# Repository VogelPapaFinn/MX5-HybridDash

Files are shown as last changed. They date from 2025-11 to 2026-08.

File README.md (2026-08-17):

# MX5-HybridDash (v2)

A hybrid instrument cluster for a *Mazda MX-5 NB*, which replaces the three small analog gauges and replaces them with 1.5" IPS displays. The project aims to look like an *OEM+* look and feel without destroying the old charm of the car.

<p align="center">
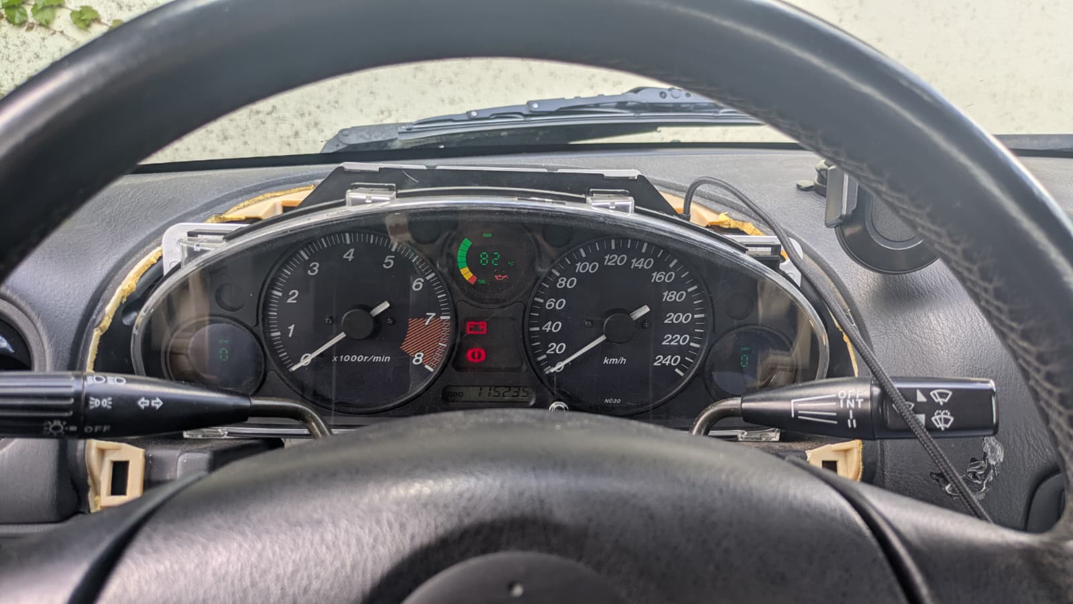
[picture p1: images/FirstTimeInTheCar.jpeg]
MX5 HybridDash Hardware
  
</p>

## Hardware

The project consists of four custom made PCBs of two types:
- A big Sensor PCB which sits on the back of the cluster, connects to the sensors & ECU and controls the displays
- Three small display PCBs which connect to the displays and receive instructions & data from the Sensor PCB

All four PCBs utilize a powerful ESP32-S3 microcontroller and the CAN bus to communicate with each other. This allows a robust communication without faulty data and provides the possiblity to expand the cluster with new hardware & features in the future-
The displays have a resolution of 360x360 on a 1.5" IPS panel, giving everything a high detailed look.

## Basic Features

Currently the displays can display:
* **RPM**
* **Speed**
* **Indicator (right & left)**
* **Oil Pressure (switch)**
* **Fuel Level**
* **Water Temperature**

This allows for example to calibrate the fuel level sensor so it is more accurate. In my car it shows that the fuel tank is empty when there are 10-15L left. Furthermore due to my size the indicators & the upper scale of the speedometer hide behind the steering wheel. By displaying them in the lower left and right display this isnt an issue anymore.

## Main Feature

My car is a pre-Facelift model and therefore does not have an OBDII connector (at least thats normal here in europe). After a lot of researching, fumbling around, reverse-engineering and testing I managed to establish a **connection** with the **OEM ECU** **without a OBDII connector**. 

At the moment I knowThis of 33 different values that are readable: *(Valus NOT Sensors, as some Sensors output multiple units)*
* **Alternator** - Load (%)
* **Alternator** - Desired Voltage (V)
* **Cabin Fan** - Toggle
* **Brake** - Toggle
* **Rear Window Defroster** - Toggle
* **Daytime Lights** - Toggle
* **Coolant** - Sensor Voltage (V)
* **Coolant** - Temperature (°C)
* **EGR** - Toggle
* **Cooling Fan Speed** - On, Slow Speed
* **Cooling Fan Speed** - On, Medium Speed
* **Cooling Fan Speed** - On, Fast Speed
* **Fuel Pump** - Toggle
* **Injector** - Injection Time (ms)
* **Battery** - Low Voltage (Light Indicator)
* **Headlight Left** - Toggle
* **Headlight Right** - Toggle
* **Idle Bypass** - Time (ms)
* **Idle Switch** - Toggle
* **Engine** - Load (%)
* **Airmass** (V)
* **Airmass** (g/s)
* **Main Relais** - Toggle
* **Engine** - Check Engine Light 
* **Airmass Pre-Cat** - Voltage (V)
* **Power Steering** - Pressure Switch Toggle
* **RPM**
* **EGR** - Valve Position
* **Ignition Timing** - Advancing (°)
* **Immobilizer** - Toggle
* **Throttle** - Voltage (V)
* **ECU** - Input Voltage (V)
* **Speed** (KMH)

## Future Plans
I plan a lot for the project even if its (software wise) stillt at the early beginning. But here is a list of features I aim to implement:
- [ ] Calibration of the sensors
- [ ] Calculation of new Values by combining the hardware & ECU sensors (e.g. current fuel consumption)
- [ ]  Webserver to control the dash
	- [ ] Reading & displaying data from the ECU
- [ ] Customizable display GUI
- [ ] Connection to the smartphone
	- [ ] Google Maps integration / direction notifications in the display GUI
	- [ ] Spotify integration
- [ ] Sensor data tracking & visualization for analyzation (e.g. on track-day use)

Please note that this are just some ideas of mine. This is not a roadmap. This is not organized by priority.

## About me

Hello! Im Finn a 21 year old computer science student from Bonn (Germany). I work as an embedded software engineer (besides my studies of course) and started tinkering around with electronics around two years ago. This project is developed exclusively in my free time for my own fun. I actually started just because I wanted to learn about electronics... Now here I am :)

## Contact

If you have any questions or anything else you are welcome to contact me. There are three possible ways (ranked by my preference):
1. send me a mail: finn.ganser@gmx.de
2. Create an issue here in this GitHub repository
3. Contact me via the Miata.net forum. Either via my linked thread or via a [private message](https://forum.miata.net/vb/member.php?u=307577)

## License

The whole project is published under the **GPLv3** license. Basically this means everybody can use, alter and provide the project, free and commercial as long as the provided code and hardware stays open source for the user. Note, that this is my conclusion of the license, before acting please read the license and its terms yourself!!

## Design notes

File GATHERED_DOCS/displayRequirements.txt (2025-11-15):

Minimum Requirements:
- Show RPM
- Show Speed
- Show Fuel level
- Show Blinkers
- Show Oil pressure
- Show Coolant temperature

- KM Total
- KM since start
- KM since last refueling
- Fuel consumption L/100km
- Fuel consumption %/100km
  
- Controlling the UI with buttons

Features which could be cool and not that complicated:
- Shift indicator
- Last shift on RPM X
- Tracking route, speed, acceleration etc. [and then send it to the smartphone or smth like that]
- 0kmh to 100kmh acceleration timer
- Welcome message on startup
- GPS speed

What would be nice but is probably not possible yet or really complicated:
- LED under needle which lights depending on the RPM/Speed/Fuel level/..
- Current fuel consumption (in this exact moment -> current fuel injection)
- Navigation from smartphone
- Show Speed limits (via GPS and web DB [Expert Level would be via live image recognition])
- Bluetooth audio connection (to radio)
- Dimming brightness with the dim switch in the car
- Configuring via App / WiFi / Website / ...
- Visual shift indicator via LEDs
- Visual last shift point via LEDs
- LED backlight for the whole cluster
- Replace the lighting icons with another display
(- Replace the old stepper motors with new ones and control them with the arduino)

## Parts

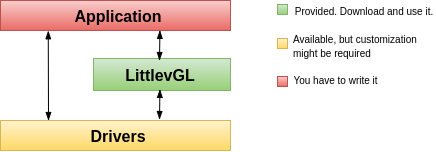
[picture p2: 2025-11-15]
SW/components/lvgl/docs/misc/sys.png

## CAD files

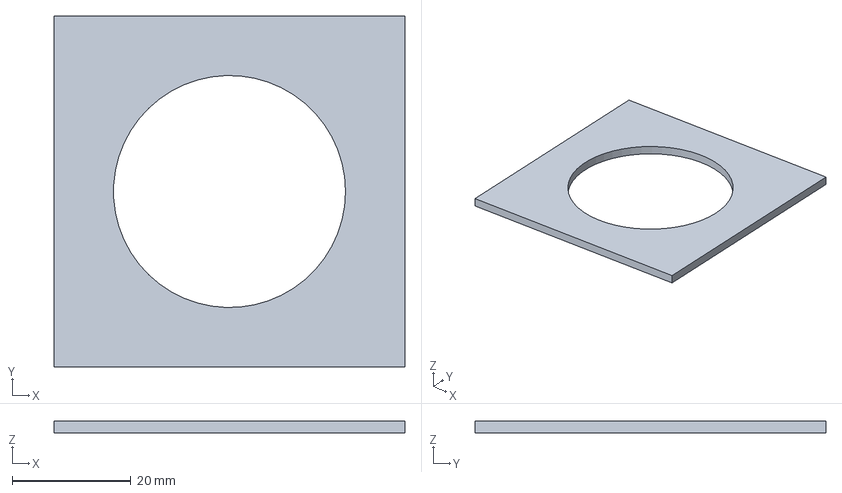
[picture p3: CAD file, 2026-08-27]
HW/3DModels/DisplayBracket.FCStd
59.0 x 59.0 x 2.00 mm

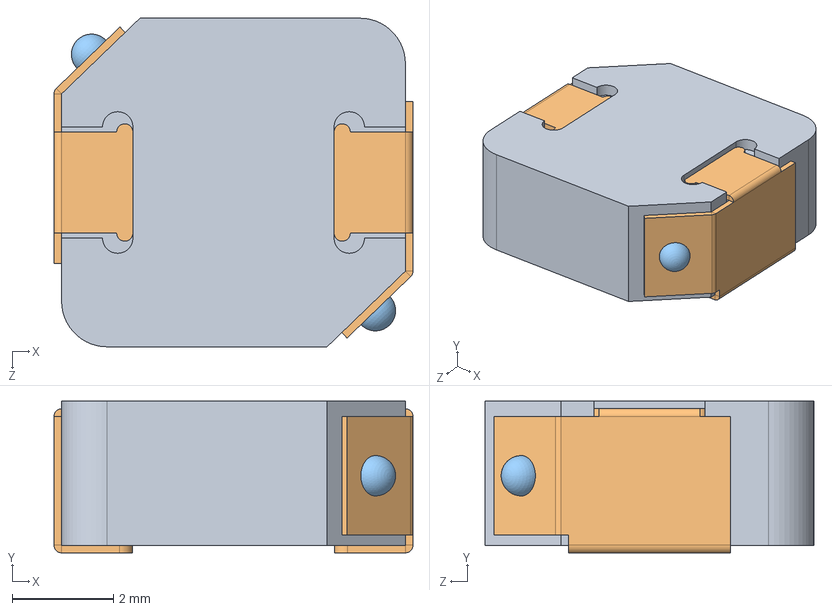
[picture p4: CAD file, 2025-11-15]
HW/Footprints/SPM6530T/SPM6530T-150M-HZ_uncolored.step
7.10 x 3.00 x 6.50 mm

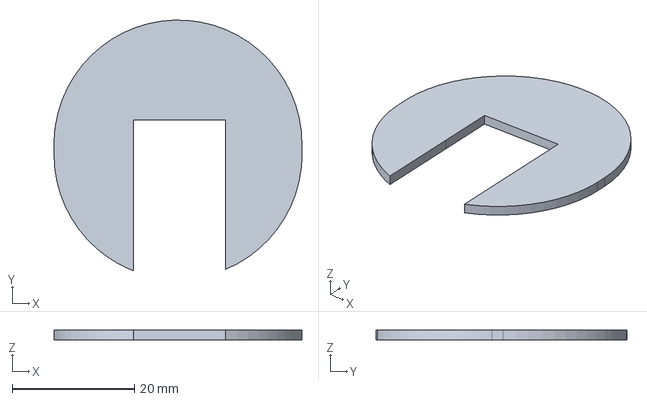
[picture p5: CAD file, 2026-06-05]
HW/3DModels/DisplaySpacer.FCStd
40.5 x 40.9 x 1.60 mm

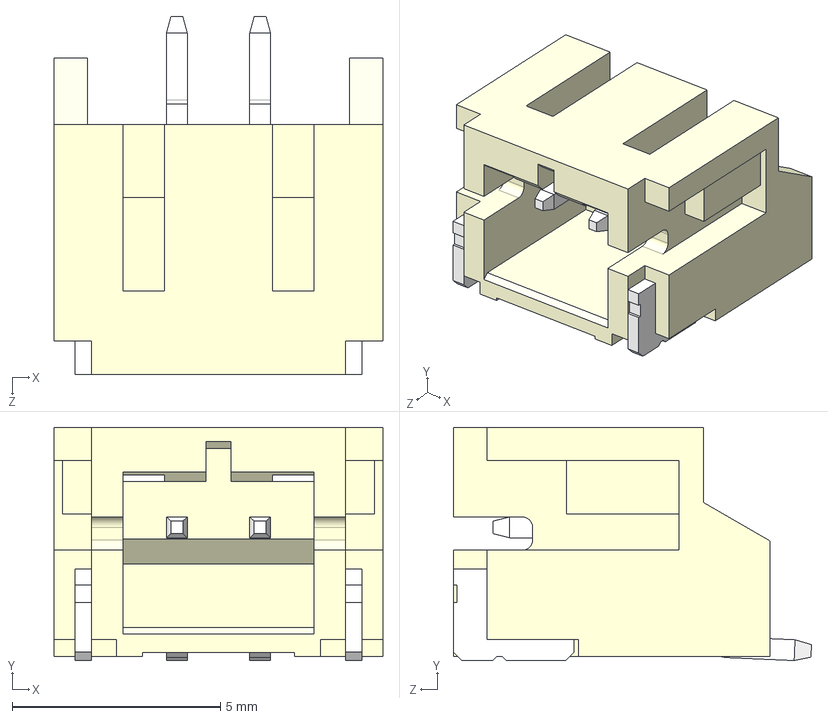
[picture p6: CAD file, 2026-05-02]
HW/3DModels/S2B-PH-SM4-TB--3DModel-STEP-269445.STEP
7.90 x 5.60 x 8.60 mm

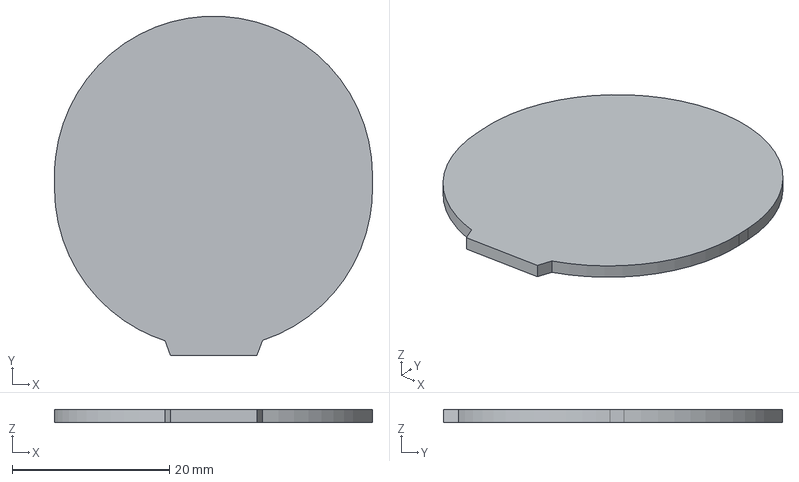
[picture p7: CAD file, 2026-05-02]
HW/3DModels/DisplayPCB.step
40.5 x 43.2 x 1.60 mm

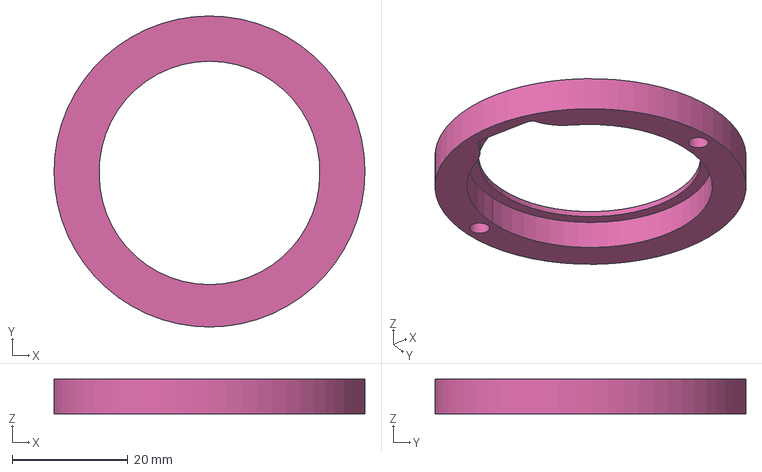
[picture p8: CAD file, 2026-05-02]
HW/3DModels/DisplayBracket-DisplayHolder.step
53.7 x 53.7 x 6.00 mm

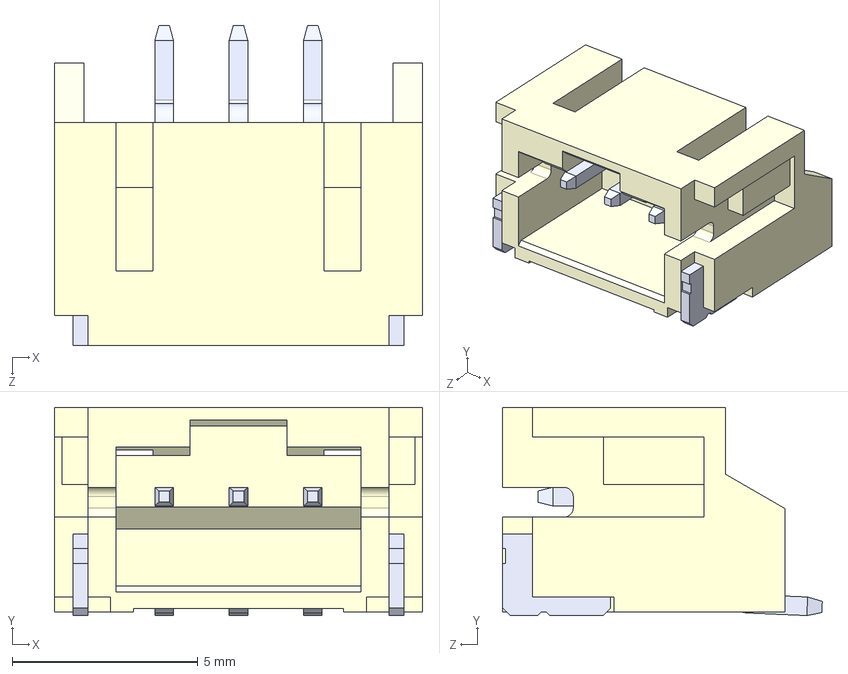
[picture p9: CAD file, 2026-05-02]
HW/3DModels/S3B-PH-SM4-TB--3DModel-STEP-269445.STEP
9.90 x 5.60 x 8.60 mm

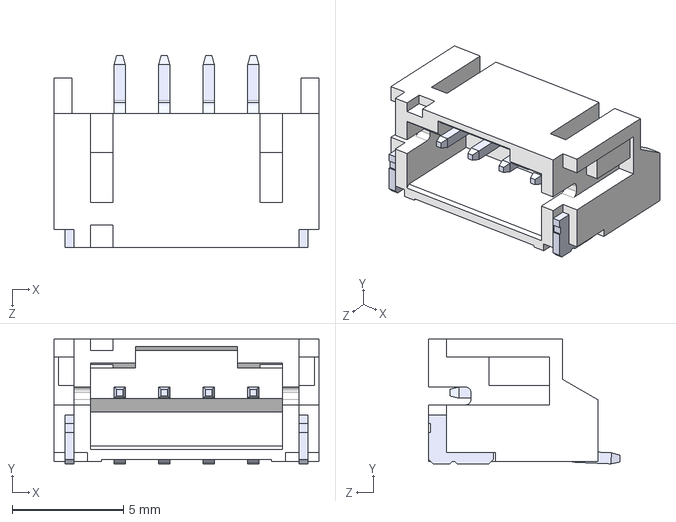
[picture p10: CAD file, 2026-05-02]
HW/3DModels/S4B-PH-SM4-TB--3DModel-STEP-56544.STEP
11.9 x 5.60 x 8.60 mm

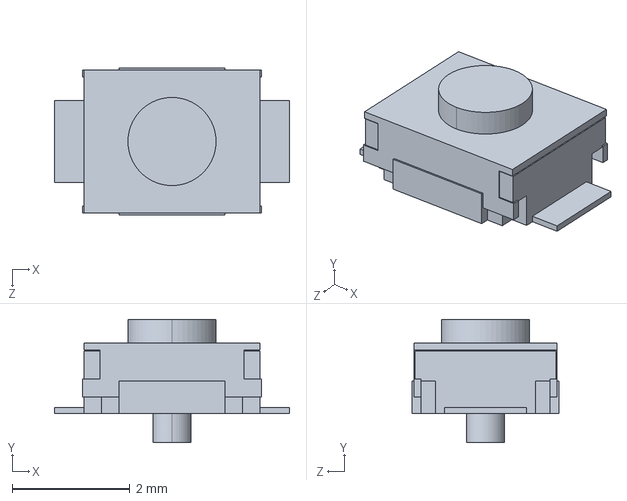
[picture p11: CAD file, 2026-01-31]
HW/3DModels/SMD_Push_Button.STEP
4.00 x 2.10 x 2.50 mm

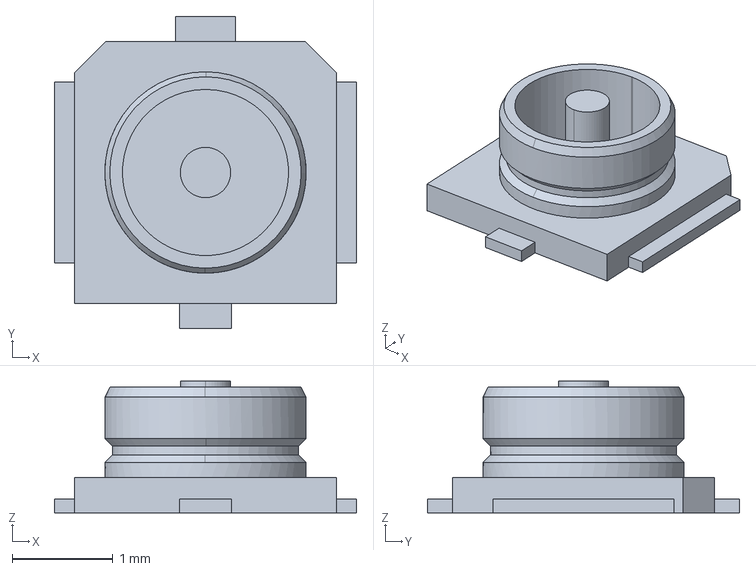
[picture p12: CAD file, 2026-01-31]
HW/3DModels/CONMHF1-SMD-G-T--3DModel-STEP-78480.STEP
3.00 x 3.10 x 1.31 mm

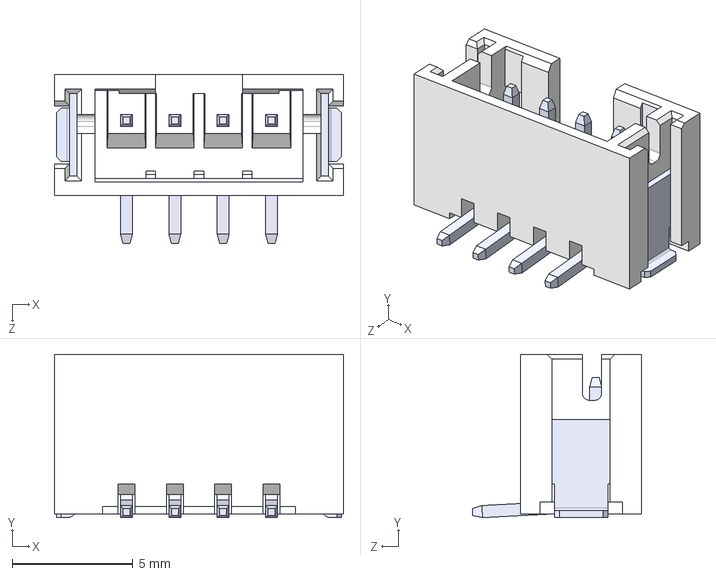
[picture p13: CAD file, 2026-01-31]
HW/3DModels/B4B-PH-SM4-TB--3DModel-STEP-510211.STEP
12.0 x 6.75 x 7.00 mm

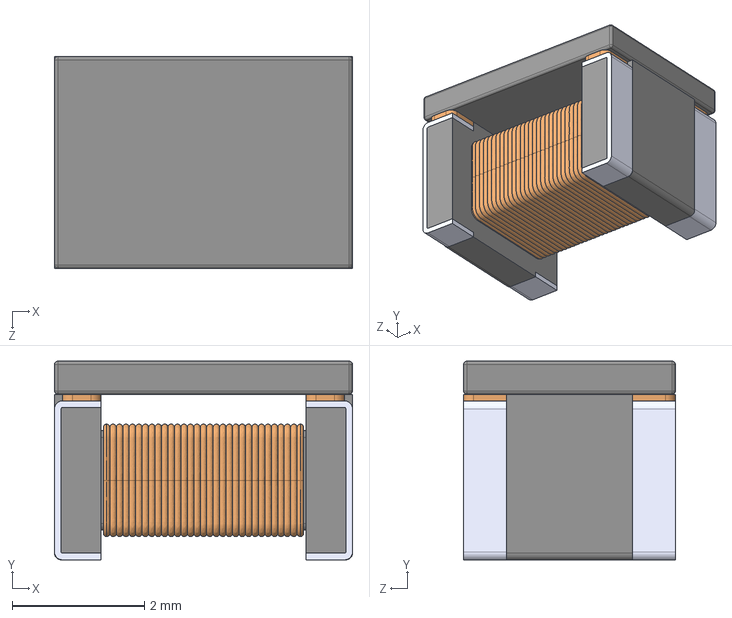
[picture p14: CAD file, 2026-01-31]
HW/3DModels/ACT45B-510-2P-TL003--3DModel-STEP-510211.STEP
4.50 x 3.00 x 3.20 mm

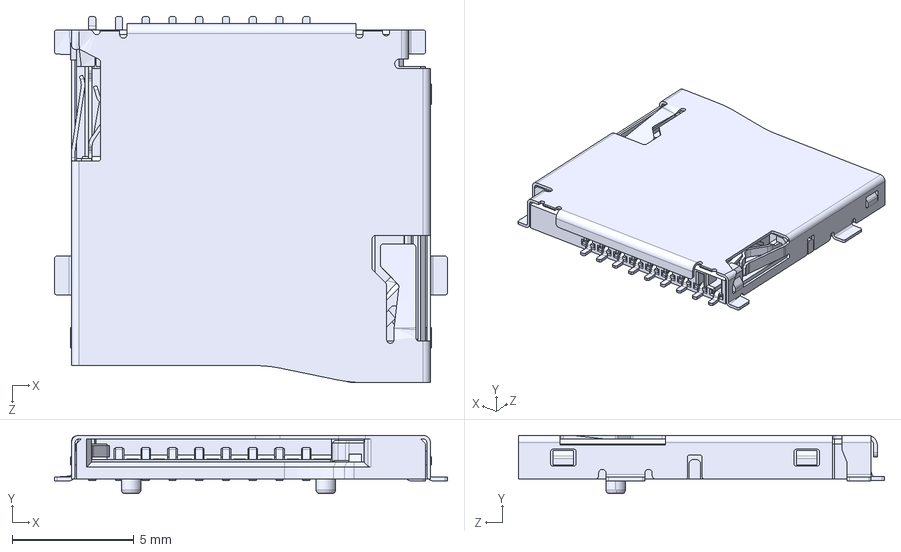
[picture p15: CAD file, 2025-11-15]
HW/3DModels/CUI_DEVICES_MSD-1-A.step
16.1 x 2.40 x 15.0 mm

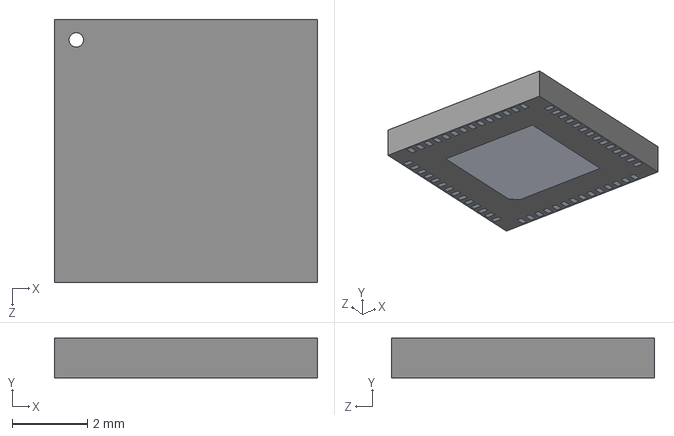
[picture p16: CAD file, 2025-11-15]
HW/3DModels/ESP32-S3-PICO-1-N8R2.step
7.00 x 1.06 x 7.00 mm

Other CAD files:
HW/3DModels/DisplayShape.FCStd
HW/3DModels/SPM6530T-150M-HZ.step
HW/3DModels/TPS5430DDAR.step
HW/3DModels/USB4105-GF-A.step
HW/3DModels/ESP32-S3-WROOM-1U 3D Model.STEP

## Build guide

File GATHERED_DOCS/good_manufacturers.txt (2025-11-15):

Allegro
Analog Devices
Broadcom
cal-chip
Diodes Incorporated
Diotec
epcos
Fairchild
Honeywell
Infineon
KEMET
KYOCERA AVX
Linear Technology
Microchip
Microsemi
Monolithic Power Systems
Motorola
Murata
National Semiconductor
Nexperia
NTE
NXP
onsemi
PANASONIC
Parallax
Renesas
Rochester Electronics
Rohm
Samsung
Sanken
Sanyo
Sharp
Stackpole
STMicroelectronics
Taiyo Yuden
TDK Electronics
TE
Texas Instruments/TI
Toshiba
Venkel
Viking Tech
Vishay
Wurth
Yageo

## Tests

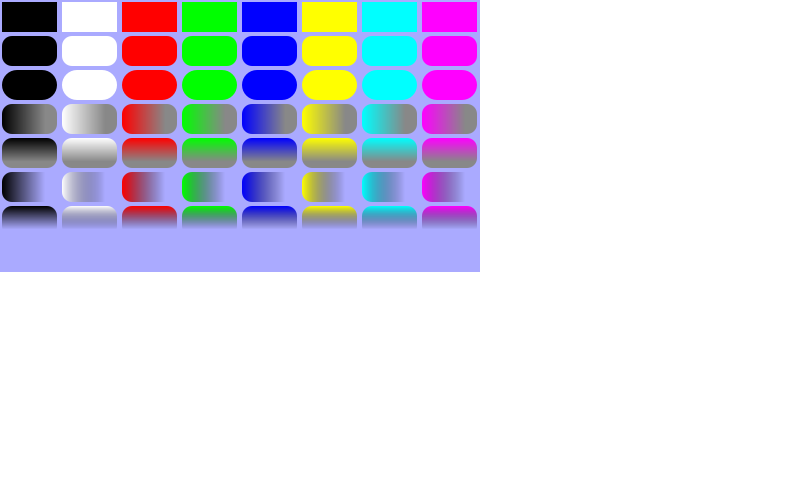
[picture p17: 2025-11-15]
SW/components/lvgl/tests/ref_imgs_vg_lite/draw/render/xrgb8888/demo_render_fill_opa_255.png

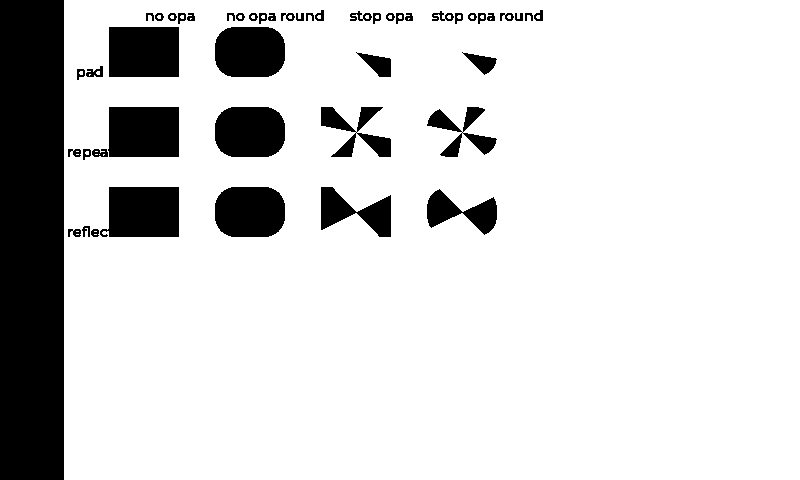
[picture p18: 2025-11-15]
SW/components/lvgl/tests/ref_imgs/draw/render/i1/demo_render_conical_gradient_opa_255.png

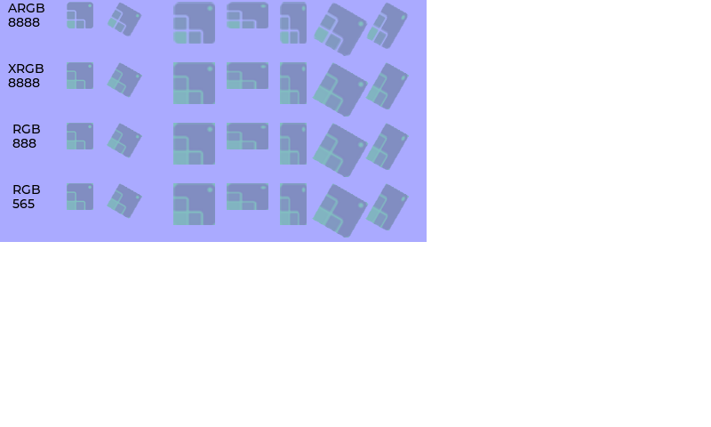
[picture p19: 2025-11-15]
SW/components/lvgl/tests/ref_imgs_vg_lite/draw/render/rgb888/demo_render_image_recolor_1_opa_128.png

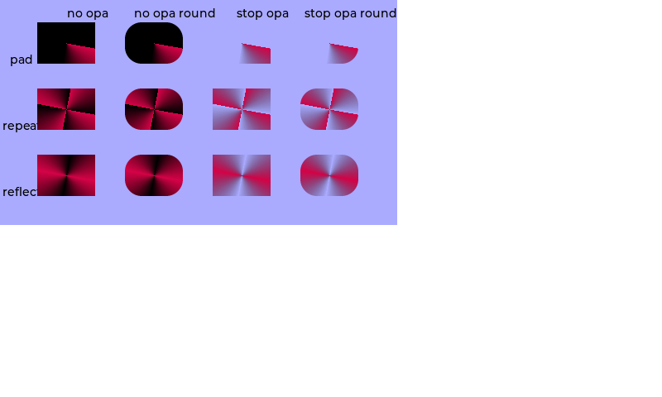
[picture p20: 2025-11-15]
SW/components/lvgl/tests/ref_imgs/draw/render/argb8888/demo_render_conical_gradient_opa_255.png

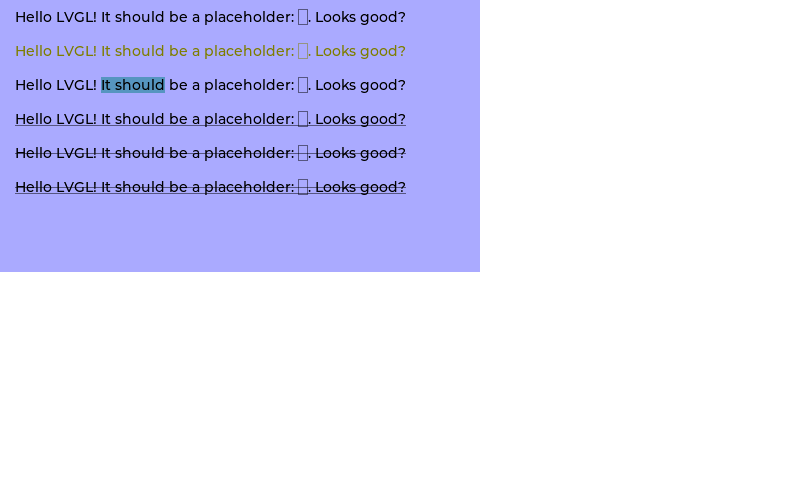
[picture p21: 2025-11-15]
SW/components/lvgl/tests/ref_imgs_vg_lite/draw/render/argb8888/demo_render_text_opa_128.png

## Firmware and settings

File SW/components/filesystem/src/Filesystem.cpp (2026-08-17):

#include "../Filesystem.hpp"

// C and C++ includes
#include <sys/stat.h>
#include <unistd.h>

// espidf includes
#include <bits/chrono.h>

#include "driver/gpio.h"

/*
 *	constexpr
 */
constexpr auto TAG = "Filesystem";

constexpr std::string SDCARD_BASE_PATH = "/sdcard";

constexpr std::string DATA_BASE_PATH = "/data";
constexpr std::string DATA_PARTITION_LABEL = "data";

constexpr std::string CONFIG_BASE_PATH = "/config";
constexpr std::string CONFIG_PARTITION_LABEL = "config";

constexpr gpio_num_t GPIO_CLK = GPIO_NUM_16;
constexpr gpio_num_t GPIO_CMD = GPIO_NUM_17;
constexpr gpio_num_t GPIO_D0 = GPIO_NUM_5;
constexpr gpio_num_t GPIO_D1 = GPIO_NUM_4;
constexpr gpio_num_t GPIO_D2 = GPIO_NUM_8;
constexpr gpio_num_t GPIO_D3 = GPIO_NUM_18;
constexpr uint8_t MAX_OPEN_FILES = 5;

/*
 *	Public Function Implementations
 */
Filesystem::Filesystem(bool mountSdCard, bool mountConfigPart, bool mountDataPart)
{
	bool warningOccured = false;
	bool errorOccured = false;

	/*
	 *	SD Card
	 */
	if (mountSdCard) {
		sdCardHost_.max_freq_khz = SDMMC_FREQ_HIGHSPEED; // 40 MHz
		sdCardHost_.slot = SDMMC_HOST_SLOT_0;

		sdCardSlotConfig_.width = 4;
		sdCardSlotConfig_.clk = GPIO_CLK;
		sdCardSlotConfig_.cmd = GPIO_CMD;
		sdCardSlotConfig_.d0 = GPIO_D0;
		sdCardSlotConfig_.d1 = GPIO_D1;
		sdCardSlotConfig_.d2 = GPIO_D2;
		sdCardSlotConfig_.d3 = GPIO_D3;

		sdCardMountConfig_.format_if_mount_failed = false;
		sdCardMountConfig_.max_files = MAX_OPEN_FILES;

		sdCardMounted_ = esp_vfs_fat_sdmmc_mount(SDCARD_BASE_PATH.c_str(), &sdCardHost_, &sdCardSlotConfig_,
												 &sdCardMountConfig_, &sdCardHandler_) == ESP_OK;
		if (sdCardMounted_) {
			ESP_LOGI(TAG, "Mounted SD Card");
		}
		else {
			ESP_LOGW(TAG, "Couldn't mount SD Card");
			warningOccured = true;
		}
	}

	/*
	 *	Data Partition
	 */
	if (mountDataPart) {
		dataPartConfig_.base_path = DATA_BASE_PATH.c_str();
		dataPartConfig_.partition_label = DATA_PARTITION_LABEL.c_str();
		dataPartConfig_.max_files = MAX_OPEN_FILES;
		dataPartConfig_.format_if_mount_failed = false;

		dataPartMounted_ = esp_vfs_spiffs_register(&dataPartConfig_) == ESP_OK;
		if (dataPartMounted_) {
			ESP_LOGI(TAG, "Mounted data partition");
		}
		else {
			ESP_LOGE(TAG, "Couldn't mount data partition");
			errorOccured = true;
		}
	}

	/*
	 *	Config Partition
	 */
	if (mountConfigPart) {
		configPartConfig_.base_path = CONFIG_BASE_PATH.c_str();
		configPartConfig_.partition_label = CONFIG_PARTITION_LABEL.c_str();
		configPartConfig_.max_files = MAX_OPEN_FILES;
		configPartConfig_.format_if_mount_failed = true;

		configPartMounted_ = esp_vfs_spiffs_register(&configPartConfig_) == ESP_OK;
		if (configPartMounted_) {
			ESP_LOGI(TAG, "Mounted config partition");
		}
		else {
			ESP_LOGE(TAG, "Couldn't mount config partition");
			errorOccured = true;
		}
	}

	if (warningOccured) {
		ESP_LOGW(TAG, "Initialized with warnings");
	}
	else if (errorOccured) {
		ESP_LOGE(TAG, "Initialized with errors");
	}
	else {
		ESP_LOGI(TAG, "Initialized");
	}
}

bool Filesystem::doesFileExist(const std::string& path, Location location) const
{
	if (!isLocationMounted(location)) {
		return false;
	}

	struct stat buffer;
	return stat(buildFullPath(path, location).c_str(), &buffer) == 0;
}

bool Filesystem::createFile(const std::string& path, const Location location)
{
	if (!isLocationMounted(location)) {
		ESP_LOGI(TAG, "Couldn't create file: Location %d not mounted", location);
		return false;
	}

	if (doesFileExist(path, location)) {
		return false;
	}

	// For whatever reason fopen crashes with test.txt. I have absolutely no clue why but it costed me quite a few
	// hours until I found the crashes are caused by this :C
	if (path == "test.txt") {
		return false;
	}

	const std::string fullPath = buildFullPath(path, location);

	FILE* file = fopen(fullPath.c_str(), "a+");
	if (file == nullptr) {
		ESP_LOGW(TAG, "Couldn't create file %s", fullPath.c_str());
		return false;
	}

	fclose(file);

	return true;
}

FILE* Filesystem::openFile(const std::string& path, const std::string& mode, Location location)
{
	if (!isLocationMounted(location)) {
		ESP_LOGI(TAG, "Couldn't open file: Location %d not mounted", location);
		return nullptr;
	}

	if (!doesFileExist(path, location)) {
		return nullptr;
	}

	const std::string fullPath = buildFullPath(path, location);

	FILE* file = fopen(fullPath.c_str(), mode.c_str());
	if (file == nullptr) {
		ESP_LOGW(TAG, "Couldn't open file %s", fullPath.c_str());
		return nullptr;
	}

	return file;
}

bool Filesystem::deleteFile(const std::string& path, const Location location)
{
	if (!isLocationMounted(location)) {
		ESP_LOGI(TAG, "Couldn't open file: Location %d not mounted", location);
		return false;
	}

	if (!doesFileExist(path, location)) {
		return false;
	}

	const std::string fullPath = buildFullPath(path, location);

	if (remove(fullPath.c_str()) != 0) {
		ESP_LOGW(TAG, "Couldn't delete file %s", fullPath.c_str());
		return false;
	}

	return true;
}

bool Filesystem::doesDirectoryExist(const std::string& path, Location location) const
{
	if (location != SD_CARD) {
		ESP_LOGW(TAG, "The spiffs file system does not support directories!");
		return false;
	}

	if (!isLocationMounted(SD_CARD)) {
		return false;
	}

	const std::string fullPath = buildFullPath(path, location);

	struct stat stats;
	stat(fullPath.c_str(), &stats);
	return S_ISDIR(stats.st_mode);
}

bool Filesystem::createDirectory(const std::string& path, Location location) const
{
	if (location != SD_CARD) {
		ESP_LOGW(TAG, "The spiffs file system does not support directories!");
		return false;
	}

	if (!isLocationMounted(SD_CARD)) {
		return false;
	}

	if (doesDirectoryExist(path, SD_CARD)) {
		return false;
	}

	const std::string fullPath = buildFullPath(path, location);

	if (mkdir(fullPath.c_str(), S_IRWXU) != 0) {
		ESP_LOGW(TAG, "Failed to create directory %s", fullPath.c_str());
		return false;
	}

	return true;
}

bool Filesystem::deleteDirectory(const std::string& path, Location location) const
{
	if (location != SD_CARD) {
		ESP_LOGW(TAG, "The spiffs file system does not support directories!");
		return false;
	}

	if (!isLocationMounted(SD_CARD)) {
		return false;
	}

	if (!doesDirectoryExist(path, SD_CARD)) {
		return false;
	}

	const std::string fullPath = buildFullPath(path, location);

	if (rmdir(fullPath.c_str()) != 0) {
		ESP_LOGW(TAG, "Couldn't delete directory %s", fullPath.c_str());
		return false;
	}

	return true;
}
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

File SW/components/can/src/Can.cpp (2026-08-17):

#include "Can.hpp"

// Project includes
#include "Events.hpp"

// espidf includes
#include "esp_event.h"
#include "esp_log.h"
#include "esp_twai.h"

/*
 *	Private constexpr
 */
constexpr auto TAG = "CanNode";

constexpr uint32_t CAN_SPEED = 1000000; // 1 Mbit/s
constexpr uint8_t CAN_QUEUE_DEPTH = 15;
constexpr uint16_t CAN_SEND_TIMEOUT_MS = 200;

/*
 *	Private Static Callback Functions
*/
static bool staticTransmittedFrameCb(twai_node_handle_t p_nodeHandle, const twai_tx_done_event_data_t* p_eventData,
									 void* p_userCtx)
{
	// Get the class context from the user arguments
	const auto can = static_cast<Can*>(p_userCtx);
	if (can == nullptr) {
		return false;
	}

	BaseType_t xHigherPriorityTaskWoken = pdFALSE;
	xQueueSendFromISR(*can->getFrameTransmittedQueue(), p_eventData->done_tx_frame, &xHigherPriorityTaskWoken);

	return xHigherPriorityTaskWoken;
}

static bool staticReceivedFrameCb(twai_node_handle_t p_nodeHandle, const twai_rx_done_event_data_t* p_eventData,
                                  void* p_userCtx)
{
	if (p_eventData == nullptr) {
		return false;
	}

	// Get the frame
	Can::Frame canFrame;
	twai_node_receive_from_isr(p_nodeHandle, &canFrame.twaiFrame);
	canFrame.fromTwaiFrame();

	// Queue it to the event loop
	esp_event_post(SYSTEM_EVENT_BASE, CAN_FRAME_RECEIVED, &canFrame, sizeof(canFrame), portMAX_DELAY);

	return false;
}

static bool staticStateChangedCb(twai_node_handle_t p_nodeHandle, const twai_state_change_event_data_t* p_eventData,
                                 void* p_userCtx)
{
	if (p_eventData == nullptr) {
		return false;
	}

	if (p_eventData->new_sta != TWAI_ERROR_BUS_OFF) {
		return false;
	}

	esp_rom_printf("State changed from %d to %d\n", p_eventData->old_sta, p_eventData->new_sta);
	// esp_rom_printf("An error occurred. Arbitration lost: %d \n Bit error: %d \n Form error: %d \n Stuff error: %d \n ACK error: %d \n val: %d", edata->err_flags.arb_lost, edata->err_flags.bit_err, edata->err_flags.form_err, edata->err_flags.stuff_err, edata->err_flags.ack_err, edata->err_flags.val);

	twai_node_recover(p_nodeHandle);

	return false;
}

/*
 *	Private Tasks
 */
static void canFrameTransmittedTask(void* p_param)
{
	if (p_param == nullptr) {
		vTaskDelete(nullptr);
	}

	auto can = static_cast<Can*>(p_param);

	twai_frame_t rxFrame;
	while (true) {
		if (xQueueReceive(*can->getFrameTransmittedQueue(), &rxFrame, portMAX_DELAY) != pdPASS) {
			continue;
		}

		can->transmittedFrameCb(rxFrame);
	}
}

/*
 *	Private Callback functions implementations
 */
void Can::transmittedFrameCb(const twai_frame_t frame)
{
	// Debug logging
	//esp_rom_printf("Transmitted frame with message id %d with buffer: ", p_eventData->done_tx_frame->header.id);
	//for (uint16_t i = 0; i < p_eventData->done_tx_frame->buffer_len; i++) {
	//	esp_rom_printf("%d ", p_eventData->done_tx_frame->buffer[i]);
	//}
	//esp_rom_printf("\n");

	if (xSemaphoreTake(pendingFramesMutex_, portMAX_DELAY) != pdTRUE) {
		return;
	}

	// Free memory
	for (uint32_t i = 0; i < pendingFrames_.size(); i++) {
		if (!pendingFrames_.at(i).get()->transmitting || pendingFrames_.at(i).get()->twaiFrame.header.id != frame.header.id) {
			continue;
		}

		auto const& pFrame = pendingFrames_.at(i).get()->twaiFrame;

		bool identical = true;

		// Header
		identical &= pFrame.header.id ==  frame.header.id;
		identical &= pFrame.header.dlc == frame.header.dlc;
		identical &= pFrame.header.brs == frame.header.brs;
		identical &= pFrame.header.esi == frame.header.esi;
		identical &= pFrame.header.fdf == frame.header.fdf;
		identical &= pFrame.header.ide == frame.header.ide;
		identical &= pFrame.header.rtr == frame.header.rtr;

		// Data
		identical &= pFrame.buffer_len == frame.buffer_len;
		if (!identical) { continue; }
		for (uint8_t j = 0; j < pFrame.buffer_len; j++) {
			identical &= pFrame.buffer[j] == frame.buffer[j];
		}

		if (!identical) { continue; }

		pendingFrames_.erase(pendingFrames_.begin() + i);

		// Unlock the mutex
		xSemaphoreGive(pendingFramesMutex_);

		return;
	}

	// Unlock the mutex
	xSemaphoreGive(pendingFramesMutex_);
}

/*
 *	Private Function implementations
 */
Can::Can(const gpio_num_t rxGpio, const gpio_num_t txGpio)
{
	rxGpio_ = rxGpio;
	txGpio_ = txGpio;

	nodeHandle_ = nullptr;

	nodeConfig_.io_cfg.rx = rxGpio_;
	nodeConfig_.io_cfg.tx = txGpio_;
	nodeConfig_.bit_timing.bitrate = CAN_SPEED;
	nodeConfig_.tx_queue_depth = CAN_QUEUE_DEPTH;
	nodeConfig_.intr_priority = ESP_INTR_FLAG_LEVEL1;

	nodeCallbacks_.on_tx_done = staticTransmittedFrameCb;
	nodeCallbacks_.on_rx_done = staticReceivedFrameCb;
	nodeCallbacks_.on_state_change = staticStateChangedCb;
	nodeCallbacks_.on_error = nullptr;

	pendingFramesMutex_ = xSemaphoreCreateMutex();
}

bool Can::initialize()
{
	if (rxGpio_ == GPIO_NUM_NC || txGpio_ == GPIO_NUM_NC) {
		return false;
	}

	if (twai_new_node_onchip(&nodeConfig_, &nodeHandle_) != ESP_OK) {
		ESP_LOGE(TAG, "Failed to initialize CAN node");
		return false;
	}

	if (twai_node_register_event_callbacks(nodeHandle_, &nodeCallbacks_, this) != ESP_OK) {
		// Cleanup
		twai_node_delete(nodeHandle_);

		ESP_LOGE(TAG, "Failed to register CAN node callbacks");
		return false;
	}

	/*
	 *	Create Task & Queue needed to handle the memory when a frame was transmitted
	 */
	frameTransmittedQueueHandle_ = xQueueCreate(CAN_QUEUE_DEPTH, sizeof(twai_frame_t));

	if (xTaskCreate(canFrameTransmittedTask, "CanFrameTransmittedTask", 2048, this, 2, &frameTransmittedTaskHandle_) != pdPASS) {
		ESP_LOGE(TAG, "Failed to create can frame transmitted task");
		esp_restart();
	}

	ESP_LOGI(TAG, "Initialized CAN node");

	return true;
}

void Can::deinitialize() const
{
	if (nodeHandle_ == nullptr) {
		return;
	}

	// There is no function for unregistering the callbacks, so simply delete the node
	twai_node_delete(nodeHandle_);

	ESP_LOGI(TAG, "Deinitialized CAN node");
}

bool Can::enable()
{
	if (nodeHandle_ == nullptr || enabled_) {
		return false;
	}

	enabled_ = twai_node_enable(nodeHandle_) == ESP_OK;
	if (!enabled_) {
		ESP_LOGE(TAG, "Failed to enable CAN node");
	}
	else {
		ESP_LOGI(TAG, "Enabled CAN node");
	}

	return enabled_;
}

void Can::queueFrame(Frame& canFrame)
{
	if (!enabled_) {
		return;
	}

	canFrame.transmitting = true;

	// ESP_LOGI(TAG, "Transmitting Frame %s", canFrame.toString().c_str());

	// Acquire the mutex lock
	if (xSemaphoreTake(pendingFramesMutex_, portMAX_DELAY) != pdTRUE) {
		return;
	}

	// Track the new frame
	pendingFrames_.push_back(std::make_shared<Frame>(canFrame));
	const auto trackedFrame = pendingFrames_.back().get();
	trackedFrame->buildTwaiFrame();

	// Unlock the mutex
	xSemaphoreGive(pendingFramesMutex_);

	if (twai_node_transmit(nodeHandle_, &trackedFrame->twaiFrame, CAN_SEND_TIMEOUT_MS) != ESP_OK) {
		ESP_LOGW(TAG, "Failed to queue CAN frame");
	}
}

QueueHandle_t* Can::getFrameTransmittedQueue()
{
	return &frameTransmittedQueueHandle_;
}

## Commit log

2025-11-16 Removed idf.bat; Updated submodules; Implemented can bus components with basic transmit/receive functionality
2025-11-23 Updated FW; Added .clang-format for espidf components;Added first few CAN Messages;Readded Logger as component;
    [CANBus_Messages.xlsx]
2025-12-08 Updated DisplayBoard Firmware; Updated SensorBoard Firmware; Implemented basic statemachine; Changed how the CAN lib works
    [CANBus_Messages.xlsx]
2026-01-04 Updated DisplayBoard and SensorBoard Firmware; Implemented CAN bus recovery request; Removed logger component; Applied clang-tidy rules
2026-01-04 Updated Display and Sensor firmware
2026-01-06 Added firmware version request CAN logic; Added deactivated CAN debugging function; Updated Sensor and Display firmware]
2026-01-09 Reworked CAN system; Removed state machine component; Updated SensorBoard and DisplayBoard firmware
2026-01-10 Updated SensorBoard firmware; Added unregister rx cb function in the CAN
2026-01-10 Changed name of CAN message; Updated Display and Sensor Board firmware
2026-01-11 Changed how the CAN passes rx frames; Fixed NULL pointer exception; Fixed brs = 1 bug
2026-01-17 Fixed a bug where received CAN data was sometimes out of scope; Updated Sensor and Display Board firmware
2026-01-19 Updated Display and Sensor Board firmware
2026-01-31 Reworked Display Board circuitry and layout
    [ACT45B-510-2P-TL003--3DModel-STEP-510211.STEP, B4B-PH-SM4-TB--3DModel-STEP-510211.STEP, CONMHF1-SMD-G-T--3DModel-STEP-78480.STEP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]
2026-02-01 Updated SensorBoard HW
2026-05-02 Added rewritten Filesystem component; Rewritten CAN component; Updated 3D Models, Footprints etc.; Added PDF for KLine protocol (communication with ECU, which is confirmed to be working but not yet i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
    [CUI_DEVICES_MSD-1-A.step, DisplayBracket-DisplayHolder.step, DisplayBracket.FCStd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]
2026-05-02 Updated DisplayPCB , SensorBoardPCB and SensorBoardFW submodules
2026-05-08 Changed CAN header structure; Fixed dangling pointer when sending data; Fixed issue where data was send but nothing was received; Updated UI
    [DisplayBracket.FCStd]
2026-05-08 Moved the Config class from the SensorBoard FW to the Filesystem component; Fixed issue in the Filesystem component
    [Filesystem.cpp]
2026-06-05 Updated CAN Driver; Updated Config File Driver; Updated EEZ Project
    [DisplayBracket.FCStd, DisplaySpacer.FCStd]
2026-06-07 Removed debugging log from CAN driver; Updated Display Firmware; Updated Sensorboard Firmware; Added MX5NB service manual;
2026-06-12 Fixed racing issue in the CAN driver; Moved Wifi driver to its own espidf component; Updated Display and Sensor Board FW
    [Can.cpp]
2026-06-13 Deactivated logging in the CAN driver; Fixed issue in the WifiHost driver; Updated Display & Sensor PCB firmware
    [Can.cpp]
2026-08-17 Complete rework of event & task system. Now using espidf event loop and FreeRTOS timers (UNTESTED!!!); Further code improvements, with the goal modulize/separater the code; Display SW not yet reworke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
    [Can.cpp, Filesystem.cpp]
2026-08-17 Fixed cashes & startup issues
    [Can.cpp]
2026-08-17 Fixed crash in the wifi drivers
2026-08-27 Simplified display registration;
    [DisplayBracket.FCStd]
2026-08-27 Updated Display and Sensor PCB firmware
2026-10-10 Added clangd file; Updated Display Bracket 3D Model (Rework needed!); Switched from espidf src clone to docker container
2026-10-10 Updated SensorBoard_FW; clang formatted Can.hpp
2026-10-10 Added clangd file; Switched to devcontainer & vscode; clang formatted Gui.hpp;
2026-10-17 Added SensorsData singleton class, which holds the newest data of each sensor; Added SensorHandler which handles the HW Sensors, updates them and writes their new values into the SensorsData object; 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
2026-10-17 Updated how the CAN Driver reports received frames
2026-10-18 WIP StateMachine implementation; WIP rework of all states; Implemented Sensor Broadcasting (UNTESTED)
2026-10-19 WIP StateMachine Implementation in the SensorBoard_FW; Reformattings
2026-10-21 Updated CAN Groups and Functions for the new states in the SensorBoard_FW; Updated MessageReceiver to prevent duplicated Code; Updated SensorBoard_FW
2026-10-23 WIP StateMachine implementation (UNTESTED!!!); Implemented Configuration state; Added default config as .hpp; "Reworked" Gui and renamed it to GuiHandler; Implemented Operation state; "Reworked" ST77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
2026-10-23 CAN observers now dont attach to a group but to CAN in general, as there can now be only one observer at a time; Updated DisplayBoard_FW and SensorBoard_FW
2026-10-24 Added print function to the Config class; Improved closing of Config class; Updated DisplayBoard_FW and SensorBoard_FW
2026-10-24 Moved ADC init from Startup State to main; Deactivated 2 out of 3 displays for debugging; Fixed issue where the FirstStartup flag wouldnt be set to false after configuring
2026-10-24 Improved toString method of Can component; Updated DisplayBoard_FW and SensorBoard_FW
2026-10-24 Tasks now dont simply get deleted but notified and end themselves to prevent memory leaks, undefined states etc.; Renames SensorsData and SensorHandler; Added new SensorBroadcaster
2026-10-24 Fixed memory leak in CAN driver; Fixed crash caused by config class; Updated both Firmwares
2026-10-30 Verified basic KLine functionality; 5-baud init not working with current IC (TJA1021 due to TX dominant timeout being too low);
2026-10-30 Removed not needed keep alive kline frame
2026-10-31 Updated ECU sensor architecture
2026-10-31 Added names of ECU sensors
2026-10-31 Implemented reading of ecu sensors; Fixed crash in the display fw;
2026-10-31 Fixed issues in the KLineMessage; Added debug login; Fixed logging of ecu sensors
2026-10-31 Fixed ECU sensor value being misinterpreted
2026-11-01 Deactivated logging in the sensor logger
2026-11-01 Fixed issue where the passive sensors are constantly at 0V; Fixed wrong ADC issue
2026-11-04 Implemented LogFileServer to download .csv files from the Sensorboard without the need to access the physical SD card; Fixed displays not restarting after faulty update
2026-11-06 Decreased Water Temperature R1 resistor and updated value pas (still off, but better. Calibrated values will come in the next few days hopefully!)
2026-11-07 Moved Indicators to own interrupt & Can frame to decrease their delay of visualization; Increased config save delay; Fixed memory leaks & potential crashes in most tasks;
2026-11-07 Added right indicator icon (instead of rotation the left one) to decrease delay further; Updated default values of speed, rpm and temperature
2026-11-07 Moved the sensor logger file index to the NVS (from the config file)
2026-11-07 Added sensor logger file index debug log output
2026-11-08 Swapped two display configuration cause it seems I wired them incorrect (swapped)
2026-11-08 The Update in the Display Bord now blocks updates of the GUI and interrupts of the ST77916 driver to prevent crashes; Increased httpd receive timeout;
2026-11-08 Increased update fail timeout and the httpd send timeout in the UpdateDisplays state; The SensorFileIndex in the NVS now does not get increased immediately but after 4 minutes, to prevent cluttering 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
2026-11-08 Implemented EMA (Exponential Moving Average) Smoothing/Filtering to the FuelLevel (untested)
2026-11-08 Updated conversion of ECU Speed sensor value
2026-11-08 Added data structure which holds the switch tests of the ECU (not yet used in the code)
2026-11-09 Implemented Serial Console to execute actuator tests (for now only switch tests are implemented) (UNTESTED!);
2026-11-09 Increased KLine timeouts; Cleared up a few switch actuator tests;
2026-11-10 Added value actuator tests (UNTESTED);
2026-11-10 Fixed crashes in the actuator tests
2026-11-10 Changed name of an ECU sensor
2026-11-10 Added boost resistor in the Fuel Level
2026-11-11 Fixed nvs being initialized too late, causing problems in the Fuel Level Hw Sensor and the SensorLogger
2026-11-11 Implemented serial console commands to read the DTC (Fault Codes) (UNTESTED); Implemented KLine Function to receive multiple responses to a single request; Moved SwSensorReader instance to the operat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
2026-11-12 Replaced spiffs with littlefs; Readded ESP_INTR_FLAG_IRAM in the SensorBoard FW; Updated partitions.csv
2026-11-12 Made log partition available in the filesystem driver; Updated Display partitions.csv; Activated core dump to flash on crash
2026-11-12 The sensor logger now logs to an internal partition (which should be power-loss save) and moves all .csv files on startup to the SD Card
2026-11-12 WIP Filesystem driver rework to make it more modular and independent; SD Card currently not working -> WIP
2026-11-12 Changed resistance in PassiveSensor to float; Added tracking of measured MilliVolts of the FuelLevel sensor; FuelLevel now uses the ATTEN 6 (<1.75V) for more accurate results; Preparations for tests,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
2026-11-13 Added hardcoded mV offset to the FuelLevel sensor, when the engine (fuel pump) is running
2026-11-13 Implemented Steinhart-Hart Formula for the Coolant Temperature from captured Data (UNTESTED)
2026-11-13 Removed Log in SensorLogger
